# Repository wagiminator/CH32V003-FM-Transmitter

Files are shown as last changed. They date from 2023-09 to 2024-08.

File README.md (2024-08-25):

# CH32V003 Stereo FM Transmitter
With the portable Li-Ion battery powered Stereo FM Transmitter you can transmit audio of any kind. Simply plug your audio source into the 3.5mm audio jack, set the desired frequency, and then tune any standard FM radio receiver to receive the signal. This device is equipped with cost-effective components, including a CH32V003J4M6 32-bit RISC-V microcontroller, a KT0803K/L transmitter IC, a 128x32 pixel OLED display (SSD1306), and a Li-Ion battery charger (TP4054).

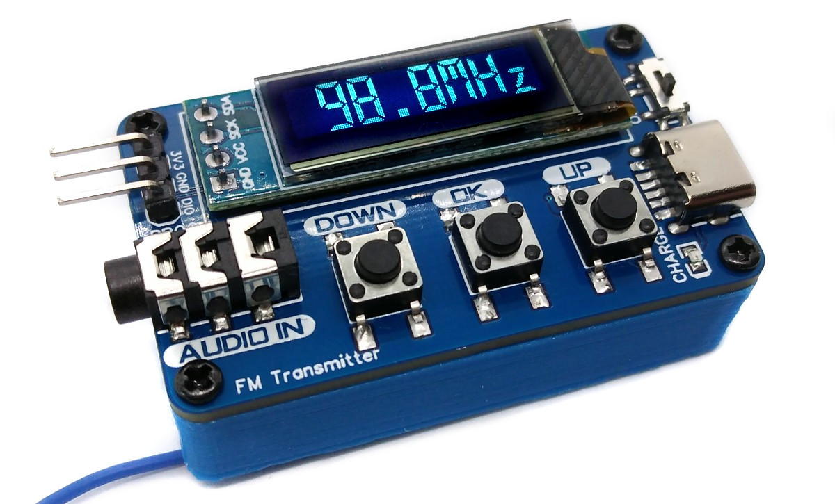
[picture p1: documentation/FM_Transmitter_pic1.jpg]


# Hardware
## Schematic
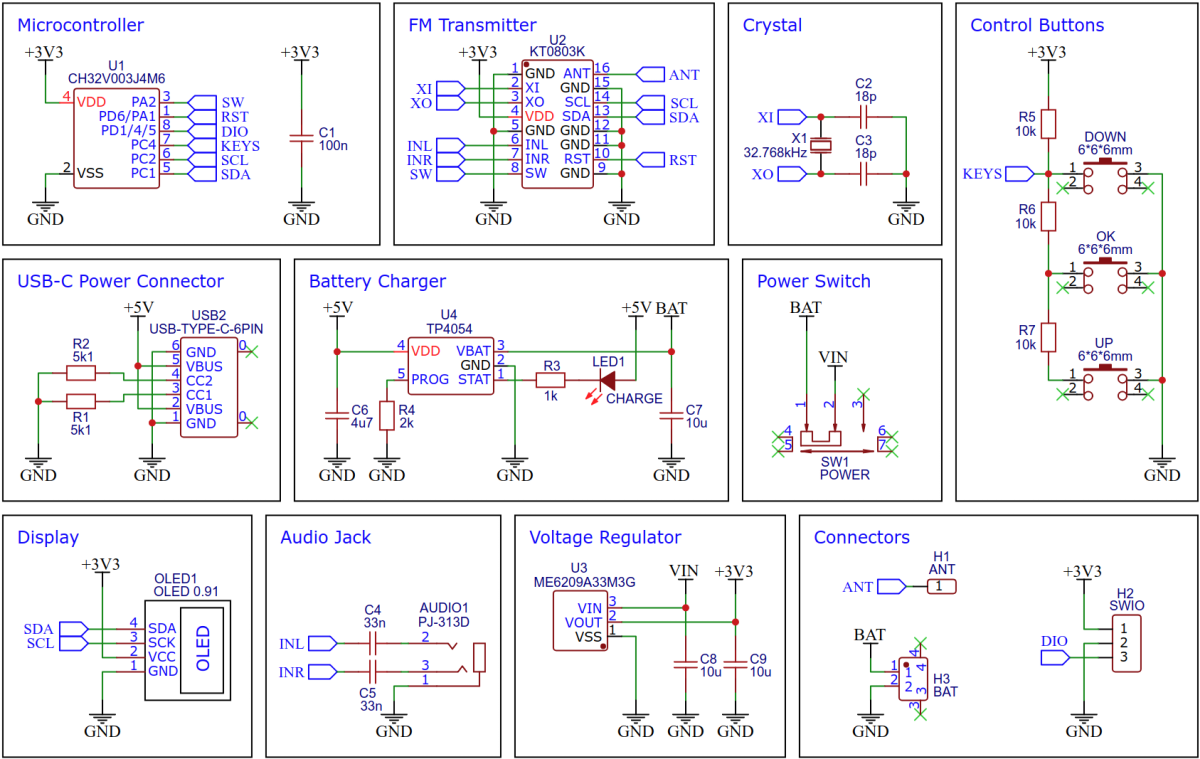
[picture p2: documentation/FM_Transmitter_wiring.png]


## The CH32V003 Family of 32-bit RISC-V Microcontrollers
The CH32V003 series is a collection of industrial-grade general-purpose microcontrollers that utilize the QingKe RISC-V2A core design supporting the RV32EC instruction set. These microcontrollers are equipped with various features such as a 48MHz system main frequency, 16KB flash, 2KB SRAM, 2.7V - 5.5V supply voltage support, a single-wire serial debug interface, low power consumption, and an ultra-small package. Additionally, the CH32V003 series includes a built-in set of components including a DMA controller, a 10-bit ADC, op-amp comparators, multiple timers, and standard communication interfaces such as USART, I2C, and SPI.

## KT0803K or KT0803L Radio-Station-on-a-Chip
The KT0803K/L is a low cost Monolithic Digital Stereo FM Transmitter, designed to process high-fidelity stereo audio signal and transmit modulated FM signal over a short range. The KT0803K/L features dual 20-bit ΔΣ audio ADCs, a high-fidelity digital stereo audio processor and a fully integrated radio frequency (RF) transmitter. An on-chip low-drop-out regulator (LDO) allows the chip to be integrated in a wide range of low-voltage battery-operated systems with power supply ranging from 1.6V to 3.6V. The KT0803K/L can be controlled via its I²C interface.

## TP4054 Li-Ion Battery Charge IC
The TP4054 is a complete constant-current/constant-voltage linear charger for single cell lithium-ion batteries. Its small package and low external component count make the TP4054 ideally suited for portable applications.

## ME6209 3.3V Linear Voltage Regulator
The ME6209 series are a group of positive voltage output, three–pin regulator, that provide a high current (max 250mA) even when the input/output voltage differential is small (80mV dropout voltage). Low power consumption (3µA quiescent current) and high accuracy (+/-2%) is achieved through CMOS technology. They allow input voltages as high as 18V.

## SSD1306 OLED Display Module
A low-cost SSD1306 4-pin I2C 128x32 pixels 0.91-inch OLED module is used as the display device. Make sure to acquire one with the correct pinout!

## Building Instructions
1. Take the Gerber files (the *zip* file inside the *hardware* folder) and upload them to a PCB (printed circuit board) manufacturer of your choice (e.g., [JLCPCB](https://jlcpcb.com/)). They will use these files to create the circuit board for your device and send it to you.
2. Once you have the PCB, you can start soldering the components onto it. Use the BOM (bill of materials) and schematic as a guide to make sure everything is connected correctly. You can find the corresponding files in the *hardware* folder. Remove the plastic part from the pin header of the OLED, trim the pins, and solder the OLED module flush onto the PCB. Solder the wire antenna to the corresponding pad on the board. A 75cm (30" = λ / 4) long 28AWG flexible silicone insulated wire works very well.

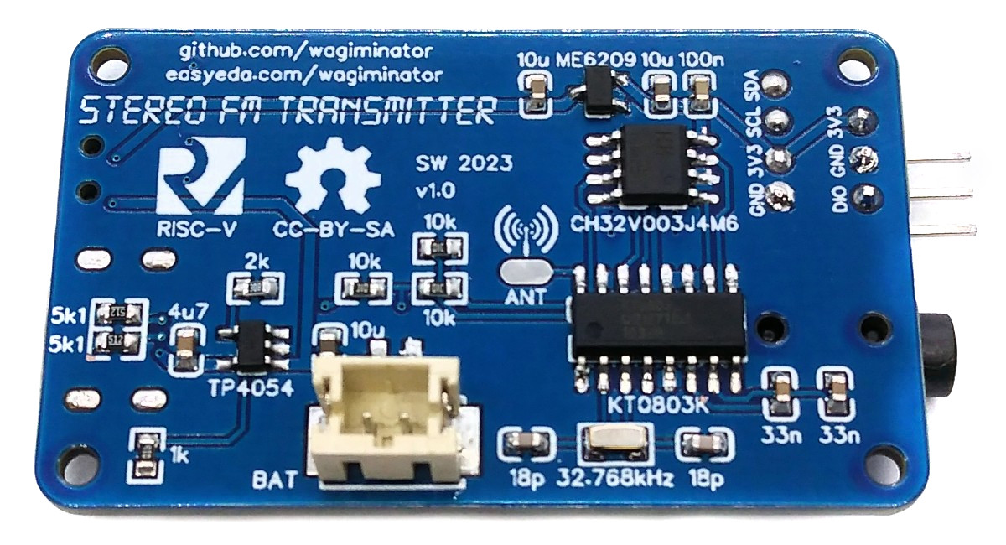
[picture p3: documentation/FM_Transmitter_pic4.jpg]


3. Upload the firmware by following the instructions in the next section (see below).
4. To create the case for your device, use the *stl* files in the *3dprint* folder with your 3D printer. Glue the battery into the case with double-sided tape. Thread the wire antenna through the small hole in the housing.

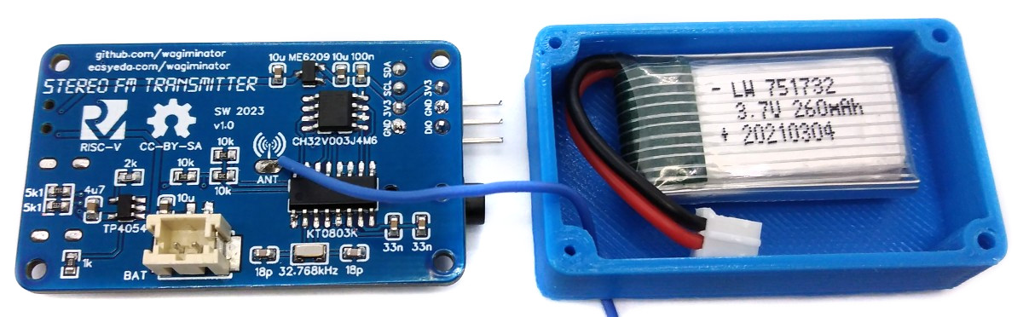
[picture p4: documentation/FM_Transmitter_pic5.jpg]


5. Connect the battery to the JST connector on the board. Pay attention to the correct polarity, unfortunately there is no standard here! Place the board on the case and screw it with four M2x5mm self-tapping screws.

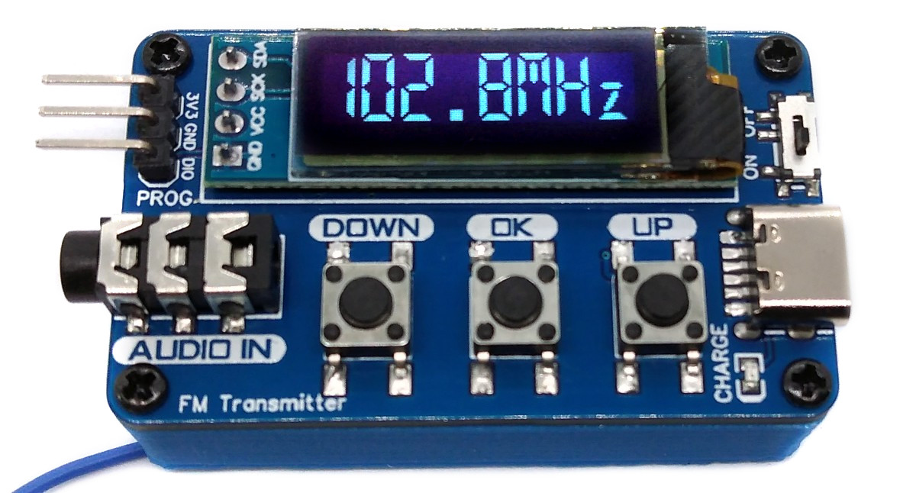
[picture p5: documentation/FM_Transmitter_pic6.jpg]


# Software
## Programming and Debugging Device
To program the CH32V003 microcontroller, you will need a special programming device which utilizes the proprietary single-wire serial debug interface (SDI). The [WCH-LinkE](http://www.wch-ic.com/products/WCH-Link.html) (pay attention to the "E" in the name) is a suitable device for this purpose and can be purchased commercially for around $4. This debugging tool is not only compatible with the CH32V003 but also with other WCH RISC-V and ARM-based microcontrollers.



To use the WCH-LinkE on Linux, you need to grant access permissions beforehand by executing the following commands:
```
echo 'SUBSYSTEM=="usb", ATTR{idVendor}=="1a86", ATTR{idProduct}=="8010", MODE="666"' | sudo tee /etc/udev/rules.d/99-WCH-LinkE.rules
echo 'SUBSYSTEM=="usb", ATTR{idVendor}=="1a86", ATTR{idProduct}=="8012", MODE="666"' | sudo tee -a /etc/udev/rules.d/99-WCH-LinkE.rules
sudo udevadm control --reload-rules
```

On Windows, if you need to you can install the WinUSB driver over the WCH interface 1 using the [Zadig](https://zadig.akeo.ie/) tool.

To upload the firmware, you need to ensure that the FM Transmitter is switched off or the battery is removed. Then, you should make the following connections to the WCH-LinkE:

```
WCH-LinkE    FM Transmitter
+-------+      +-------+
|  SWDIO| <--> |DIO    |
|    GND| ---> |GND    |
|    3V3| ---> |3V3    |
+-------+      +-------+
```

If the blue LED on the WCH-LinkE remains illuminated once it is connected to the USB port, it means that the device is currently in ARM mode and must be switched to RISC-V mode initially. There are a few ways to accomplish this:
- You can utilize the Python command-line tool [rvprog](https://pypi.org/project/rvprog/) (with *-v* option).
- Alternatively, you can select "WCH-LinkRV" in the software provided by WCH, such as MounRiver Studio or WCH-LinkUtility.
- Another option is to hold down the ModeS button on the device while plugging it into the USB port.

More information can be found in the [WCH-Link User Manual](http://www.wch-ic.com/downloads/WCH-LinkUserManual_PDF.html).

## Compiling and Uploading Firmware using the Makefile
### Linux
Install the toolchain (GCC compiler, Python3, and rvprog):
```
sudo apt install build-essential libnewlib-dev gcc-riscv64-unknown-elf
sudo apt install python3 python3-pip
pip install rvprog
```

Switch off the FM Transmitter or remove the battery. Connect the FM Transmitter via the 3-pin PROG header to the WCH-LinkE programming device. Open a terminal and navigate to the folder with the *makefile*. Run the following command to compile and upload:
```
make flash
```

### Other Operating Systems
Follow the instructions on [CNLohr's ch32v003fun page](https://github.com/cnlohr/ch32v003fun/wiki/Installation) to set up the toolchain on your respective operating system (for Windows, use WSL). Also, install [Python3](https://www.pythontutorial.net/getting-started/install-python/) and [rvprog](https://pypi.org/project/rvprog/). Compile and upload with "make flash". Note that I only have Debian-based Linux and have not tested it on other operating systems.

## Compiling and Uploading Firmware using PlatformIO
- Install [PlatformIO](https://platformio.org) and [platform-ch32v](https://github.com/Community-PIO-CH32V/platform-ch32v). Follow [these instructions](https://pio-ch32v.readthedocs.io/en/latest/installation.html) to do so. Linux/Mac users may also need to install [pyenv](https://realpython.com/intro-to-pyenv).
- Click on "Open Project" and select the firmware folder with the *platformio.ini* file.
- Switch off the FM Transmitter or remove the battery. Connect the FM Transmitter via the 3-pin PROG header to the WCH-LinkE programming device. Then click "Upload".

## Uploading pre-compiled Firmware Binary
WCH offers the free but closed-source software [WCH-LinkUtility](https://www.wch.cn/downloads/WCH-LinkUtility_ZIP.html) to upload the precompiled hex-file with Windows. Select the "WCH-LinkRV" mode in the software, open the *fm_transmitter.hex* file in the *bin* folder and upload it to the microcontroller.

Alternatively, there is an open-source tool called [minichlink](https://github.com/cnlohr/ch32v003fun/tree/master/minichlink) developed by Charles Lohr (CNLohr). It can be used with Windows, Linux and Mac.

If you have installed [Python3](https://www.pythontutorial.net/getting-started/install-python/) on your system, you can also use the platform-independent open-source command-line tool [rvprog](https://pypi.org/project/rvprog/) for uploading:
```
rvprog -f bin/fm_transmitter.bin
```

# Operating Instructions
1. Make sure that the wire antenna is laid as straight as possible horizontally or vertically.
2. Turn on the transmitter using the power switch.
3. Use the OK key to switch between transmitter frequency and audio gain display/control mode.
4. Use the UP or DOWN key to increase/decrease frequency/gain.
5. If the battery is weak, recharge it via the USB-C port.

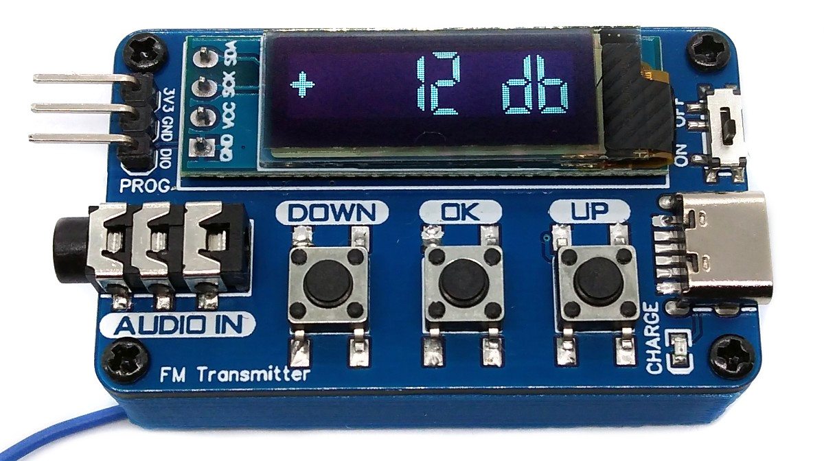
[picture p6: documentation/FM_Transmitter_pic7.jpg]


If you don't have an FM radio receiver and/or you want to build one yourself, take a look [here](https://github.com/wagiminator/CH32V003-FM-Receiver).

# References, Links and Notes
- [EasyEDA Design Files](https://oshwlab.com/wagiminator)
- [CNLohr: ch32003fun](https://github.com/cnlohr/ch32v003fun)
- [WCH: CH32V003 datasheets](http://www.wch-ic.com/products/CH32V003.html)
- [WCH: WCH-Link user manual](http://www.wch-ic.com/downloads/WCH-LinkUserManual_PDF.html)
- [WCH: Official Store on AliExpress](https://wchofficialstore.aliexpress.com)
- [KTMicro: KT0803K datasheet](https://www.elechouse.com/elechouse/images/product/FM%20Transmitter%20Module/KT0803K.pdf)
- [KTMicro: KT0803L datasheet](http://radio-z.ucoz.lv/kt_0803/KT0803L_V1.3.pdf)
- [Microne: ME6209 datasheet](https://datasheet.lcsc.com/lcsc/1811081822_MICRONE-Nanjing-Micro-One-Elec-ME6209A33M3G_C83508.pdf)
- [TP4054 datasheet](https://media.digikey.com/pdf/Data%20Sheets/UTD%20Semi%20PDFs/TP4054.pdf)
- [SSD1306 datasheet](https://cdn-shop.adafruit.com/datasheets/SSD1306.pdf)
- [128x32 OLED on Aliexpress](http://aliexpress.com/wholesale?SearchText=128+32+0.91+oled)
- [CH32V003 FM Radio Receiver](https://github.com/wagiminator/CH32V003-FM-Receiver)

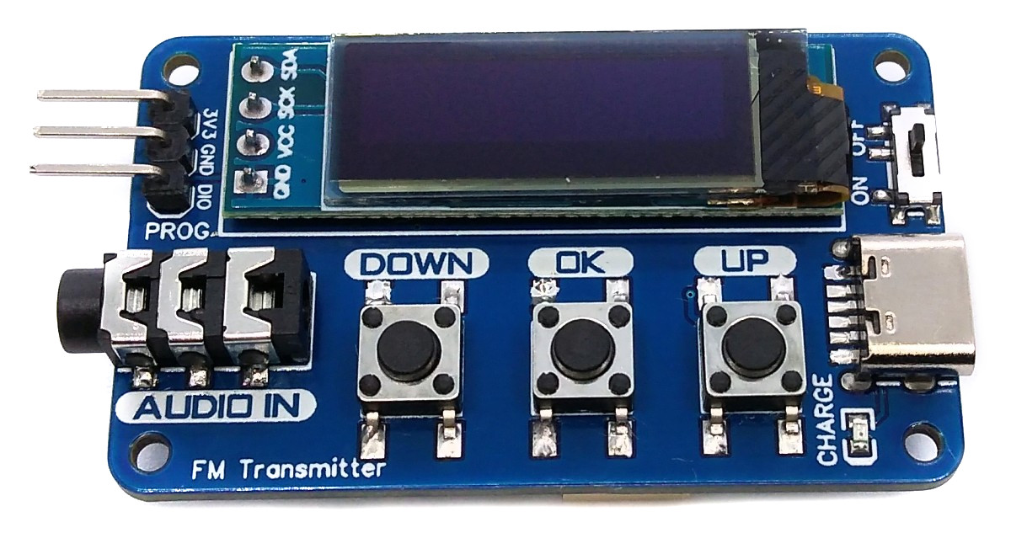
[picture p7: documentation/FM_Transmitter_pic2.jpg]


# License



This work is licensed under Creative Commons Attribution-ShareAlike 3.0 Unported License. 
(http://creativecommons.org/licenses/by-sa/3.0/)

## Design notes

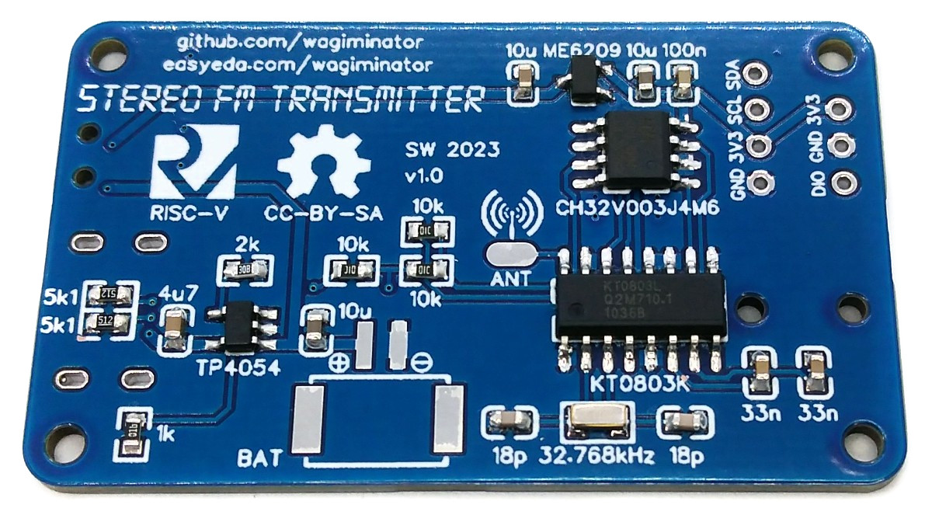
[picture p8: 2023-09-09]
documentation/FM_Transmitter_pic3.jpg

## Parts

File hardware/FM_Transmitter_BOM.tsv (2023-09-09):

ID | Name | Designator | Footprint | Quantity | Manufacturer Part | Manufacturer | Supplier | Supplier Part
1 | PJ-313D | AUDIO1 | AUDIO-SMD_PJ-313D | 1 | PJ-313D | HRO | LCSC | C95463
2 | 100n | C1 | C_0603 | 1 | CC0603KRX7R9BB104 | YAGEO | LCSC | C14663
3 | 18p | C2,C3 | C_0603 | 2 | CL10C180JB8NNNC | SAMSUNG(三星) | LCSC | C1647
4 | 33n | C4,C5 | C_0603 | 2 | CL10B333KB8NNNC | SAMSUNG(三星) | LCSC | C21117
5 | 4u7 | C6 | C_0603 | 1 | CL10A475KO8NNNC | SAMSUNG | LCSC | C19666
6 | 10u | C7,C8,C9 | C_0603 | 3 | CL10A106KP8NNNC | SAMSUNG | LCSC | C19702
7 | 6*6*6mm | DOWN,OK,UP | KEY-6.0*6.0 | 3 | SMD Tactile Switch6*6*6mm | ReliaPro | LCSC | C23873
8 | ANT | H1 | PAD_1 | 1 |  |  | LCSC | C81276
9 | SWIO | H2 | 210S-3X1/2.54 | 1 | Header2.54mm 1*3P | BOOMELE | LCSC | C49257
10 | BAT | H3 | CONN-SMD_2P_PH2.0_LT | 1 | PH2.0-2P | BOOMELE | LCSC | C64658
11 | CHARGE | LED1 | LED_0603 | 1 | KT-0603R | KENTO | LCSC | C2286
12 | OLED 0.91 | OLED1 | I2C OLED 0.91 | 1 | SSD1306 I2C OLED
13 | 5k1 | R1,R2 | 0603 | 2 | 0603WAF5101T5E | UniOhm | LCSC | C23186
14 | 1k | R3 | 0603 | 1 | 0603WAF1001T5E | UniOhm | LCSC | C21190
15 | 2k | R4 | 0603 | 1 | 0603WAF2001T5E | UniOhm | LCSC | C22975
16 | 10k | R5,R6,R7 | 0603 | 3 | 0603WAF1002T5E | UNI-ROYAL(厚声) | LCSC | C25804
17 | POWER | SW1 | SW-SMD_SS-1290L-GLL-1.5MM | 1 | SS-1290L-GL L=1.5mm | RI SHENG | LCSC | C695418
18 | CH32V003J4M6 | U1 | SOP-8_150MIL | 1 | CH32V003J4M6 | WCH(Jiangsu Qin Heng) | LCSC | C5346354
19 | KT0803K | U2 | SOP-16_150MIL | 1 |  | KTMicro
20 | ME6209A33M3G | U3 | SOT-23-3_W | 1 | ME6209A33M3G | MICRONE | LCSC | C83508
21 | TP4054 | U4 | SOT-23-5_BR | 1 | TP4054 | UMW(广东友台半导体) | LCSC | C668215
22 | USB-TYPE-C-6PIN | USB2 | USB-C-SMD-6P | 1 | TYPE-C-31-M-17 | Korean Hroparts Elec | LCSC | C283540
23 | 32.768kHz | X1 | OSC-SMD_3215 | 1 | AH03270014 | TXC Corp | LCSC | C409356

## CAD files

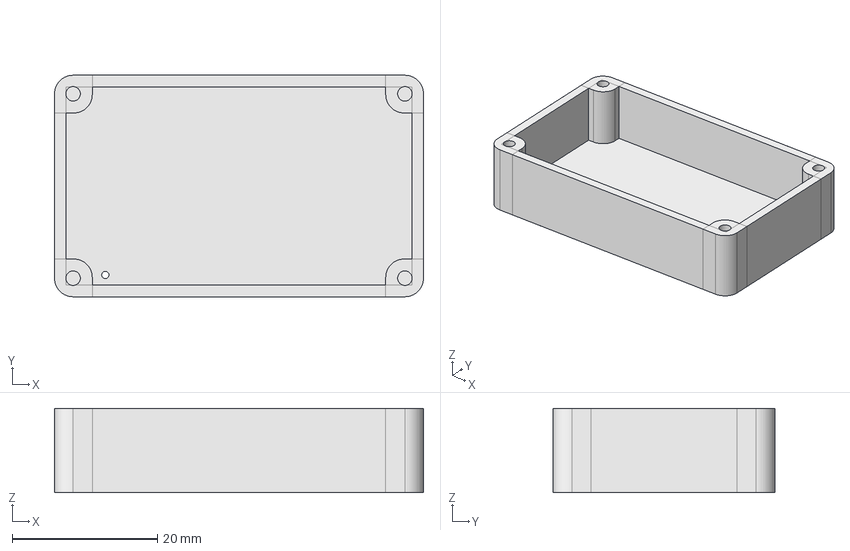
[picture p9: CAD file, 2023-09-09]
3dprint/FM_Transmitter.fcstd
50.8 x 30.5 x 11.6 mm

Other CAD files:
3dprint/FM_Transmitter.stl

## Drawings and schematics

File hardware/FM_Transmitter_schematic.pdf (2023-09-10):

# RST 10 GND 11 GND 12 SDA 13 SCL 14 GND 15 ANT 16

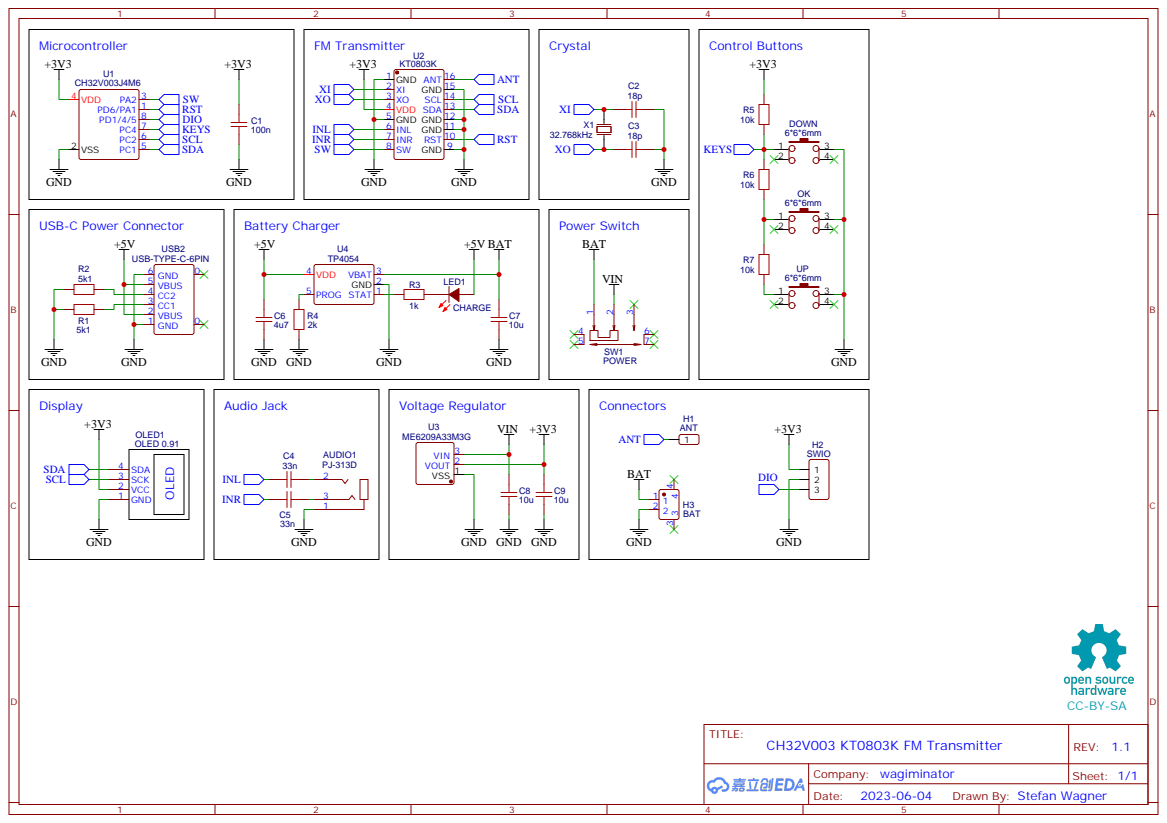
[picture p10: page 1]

Drawn By: Stefan Wagner

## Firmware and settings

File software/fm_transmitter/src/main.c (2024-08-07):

// ===================================================================================
// Project:   CH32V003 + KT0803 K/L FM Transmitter
// Version:   v1.1
// Year:      2023
// Author:    Stefan Wagner
// Github:    https://github.com/wagiminator
// EasyEDA:   https://easyeda.com/wagiminator
// License:   http://creativecommons.org/licenses/by-sa/3.0/
// ===================================================================================
//
// Description:
// ------------
// Pocket Stereo FM Transmitter.
//
// References:
// -----------
// - CNLohr ch32v003fun: https://github.com/cnlohr/ch32v003fun
// - WCH Nanjing Qinheng Microelectronics: http://wch.cn
//
// Compilation Instructions:
// -------------------------
// - Make sure GCC toolchain (gcc-riscv64-unknown-elf, newlib) and Python3 with rvprog
//   are installed. In addition, Linux requires access rights to WCH-LinkE programmer.
// - Connect the WCH-LinkE programmer to the PROG-header of the device.
// - Run 'make flash'.


// ===================================================================================
// Libraries, Definitions and Macros
// ===================================================================================
#include <system.h>           // system functions
#include <gpio.h>             // GPIO functions
#include <kt0803.h>           // KT0803 functions
#include <ssd1306_txt.h>      // OLED functions

#define PIN_SW    PA2         // KT0803 switch on/off
#define PIN_RST   PA1         // KT0803 reset (active low)
#define PIN_KEYS  PC4         // Control keys

uint8_t  display = 0;         // current display/control mode (0: frequency, 1: gain)
uint8_t  gain = 3;            // current gain (0..6)
uint16_t freq = 988;          // current frequency (in 100kHz steps, 988 means 98.8Mhz) 

// ===================================================================================
// OLED Bitmaps
// ===================================================================================

// "MHz" 44x32 pixel segment font
const uint8_t OLED_MHZ[] = {
  0xFC, 0xF9, 0xF3, 0x07, 0x07, 0xE7, 0xF7, 0xE7, 0x07, 0x07, 0xF3, 0xF9, 0xFC, 0x00, 0x00, 0x00,
  0xFC, 0xF8, 0xF0, 0x00, 0x00, 0x00, 0x00, 0x00, 0x00, 0x00, 0xF0, 0xF8, 0xFC, 0x00, 0x00, 0x00,
  0x00, 0x00, 0x00, 0x00, 0x00, 0x00, 0x00, 0x00, 0x00, 0x00, 0x00, 0x00, 
  0x7F, 0x3F, 0x1F, 0x00, 0x00, 0x1F, 0x3F, 0x1F, 0x00, 0x00, 0x1F, 0x3F, 0x7F, 0x00, 0x00, 0x00,
  0x7F, 0x3F, 0x9F, 0xC0, 0xC0, 0xC0, 0xC0, 0xC0, 0xC0, 0xC0, 0x9F, 0x3F, 0x7F, 0x00, 0x00, 0x00,
  0x00, 0x80, 0xC0, 0xC0, 0xC0, 0xC0, 0xC0, 0xC0, 0xC0, 0x80, 0x00, 0x00, 
  0xFF, 0xFE, 0xFC, 0x00, 0x00, 0x00, 0x00, 0x00, 0x00, 0x00, 0xFC, 0xFE, 0xFF, 0x00, 0x00, 0x00,
  0xFF, 0xFE, 0xFC, 0x01, 0x01, 0x01, 0x01, 0x01, 0x01, 0x01, 0xFC, 0xFE, 0xFF, 0x00, 0x00, 0x00,
  0x00, 0x00, 0x01, 0x81, 0xE1, 0xF9, 0x7D, 0x1D, 0x01, 0x00, 0x00, 0x00, 
  0x1F, 0x0F, 0x07, 0x00, 0x00, 0x00, 0x00, 0x00, 0x00, 0x00, 0x07, 0x0F, 0x1F, 0x00, 0x00, 0x00,
  0x1F, 0x0F, 0x07, 0x00, 0x00, 0x00, 0x00, 0x00, 0x00, 0x00, 0x07, 0x0F, 0x1F, 0x00, 0x00, 0x00,
  0x40, 0x60, 0x76, 0x77, 0x73, 0x71, 0x70, 0x70, 0x70, 0x60, 0x40, 0x00
};

// "db" 29x32 pixel segment font
const uint8_t OLED_DB[] = {
  0x00, 0x00, 0x00, 0x00, 0x00, 0x00, 0x00, 0x00, 0x00, 0x00, 0xF0, 0xF8, 0xFC, 0x00, 0x00, 0x00,
  0xFC, 0xF8, 0xF0, 0x00, 0x00, 0x00, 0x00, 0x00, 0x00, 0x00, 0x00, 0x00, 0x00, 
  0x00, 0x00, 0x80, 0xC0, 0xC0, 0xC0, 0xC0, 0xC0, 0xC0, 0xC0, 0x9F, 0x3F, 0x7F, 0x00, 0x00, 0x00,
  0x7F, 0x3F, 0x9F, 0xC0, 0xC0, 0xC0, 0xC0, 0xC0, 0xC0, 0xC0, 0x80, 0x00, 0x00, 
  0xFF, 0xFE, 0xFC, 0x01, 0x01, 0x01, 0x01, 0x01, 0x01, 0x01, 0xFC, 0xFE, 0xFF, 0x00, 0x00, 0x00,
  0xFF, 0xFE, 0xFC, 0x01, 0x01, 0x01, 0x01, 0x01, 0x01, 0x01, 0xFC, 0xFE, 0xFF, 
  0x1F, 0x4F, 0x67, 0x70, 0x70, 0x70, 0x70, 0x70, 0x70, 0x70, 0x67, 0x4F, 0x1F, 0x00, 0x00, 0x00,
  0x1F, 0x4F, 0x67, 0x70, 0x70, 0x70, 0x70, 0x70, 0x70, 0x70, 0x67, 0x4F, 0x1F
};

// "-" 13x32 pixel segment font
const uint8_t OLED_MINUS[] = {
  0x00, 0x00, 0x00, 0x00, 0x00, 0x00, 0x00, 0x00, 0x00, 0x00, 0x00, 0x00, 0x00, 
  0x00, 0x00, 0x80, 0xC0, 0xC0, 0xC0, 0xC0, 0xC0, 0xC0, 0xC0, 0x80, 0x00, 0x00, 
  0x00, 0x00, 0x00, 0x01, 0x01, 0x01, 0x01, 0x01, 0x01, 0x01, 0x00, 0x00, 0x00, 
  0x00, 0x00, 0x00, 0x00, 0x00, 0x00, 0x00, 0x00, 0x00, 0x00, 0x00, 0x00, 0x00
};

// "+" 13x32 pixel segment font
const uint8_t OLED_PLUS[] = {
  0x00, 0x00, 0x00, 0x00, 0x00, 0x00, 0x00, 0x00, 0x00, 0x00, 0x00, 0x00, 0x00, 
  0x00, 0x80, 0xC0, 0xC0, 0xC0, 0xFC, 0xFE, 0xFC, 0xC0, 0xC0, 0xC0, 0x80, 0x00, 
  0x00, 0x00, 0x01, 0x01, 0x01, 0x1F, 0x3F, 0x1F, 0x01, 0x01, 0x01, 0x00, 0x00, 
  0x00, 0x00, 0x00, 0x00, 0x00, 0x00, 0x00, 0x00, 0x00, 0x00, 0x00, 0x00, 0x00
};

// ===================================================================================
// OLED Update Function
// ===================================================================================
void OLED_update(void) {
  OLED_cursor(0, 0);

  // Display current volume gain level
  if(display) {
    OLED_drawBitmap((gain < 3 ? OLED_MINUS : OLED_PLUS), 13, 4);
    if      (gain == 3)                 OLED_printSegment( 0, 4, 1, 0);
    else if((gain == 0) || (gain == 6)) OLED_printSegment(12, 4, 1, 0);
    else if((gain == 1) || (gain == 5)) OLED_printSegment( 8, 4, 1, 0);
    else                                OLED_printSegment( 4, 4, 1, 0);
    OLED_clearRect(21, 32);
    OLED_drawBitmap(OLED_DB, 29, 4);
  }

  // Display current transmitter frequency
  else {
    OLED_printSegment(freq, 4, 1, 1);
    OLED_clearRect(13, 32);
    OLED_drawBitmap(OLED_MHZ, 44, 4);
  }
}

// ===================================================================================
// Button Read Function
// ===================================================================================
enum { KEY_NO, KEY_UP, KEY_OK, KEY_DOWN };
uint16_t KEY_ADC[] = { 850, 590, 250, 0 };

uint8_t KEY_read(void) {
  uint8_t  ckey = 0;
  uint16_t ckeyval = ADC_read();
  while(ckeyval < KEY_ADC[ckey]) ckey++;
  return ckey;
}

// ===================================================================================
// Main Function
// ===================================================================================
int main(void) {
  // Lokal variables
  uint8_t  i;
  uint8_t  key;
  uint8_t  keydelay;

  // Setup pins
  PIN_output(PIN_SW);
  PIN_output(PIN_RST);
  PIN_input_AN(PIN_KEYS);
  PIN_high(PIN_SW);
  PIN_high(PIN_RST);

  // Setup internal peripherals
  I2C_init();
  ADC_init();
  ADC_slow();
  ADC_input(PIN_KEYS);

  // Setup external peripherals
  OLED_init();
  OLED_clear();
  OLED_update();
  DLY_ms(500);
  KT_setFreq(freq);
  KT_setGain(gain);

  // Loop
  while(1) {
    // Read current key
    key = KEY_read();

    // Volume gain display/control mode
    if(display) {
      switch(key) {
        case KEY_UP:    if(gain < 6) KT_setGain(++gain); break;
        case KEY_DOWN:  if(gain > 0) KT_setGain(--gain); break;
        case KEY_OK:    display = 0; break;
        default:        break;
      }
      if(key) {
        OLED_update();
        while(KEY_read());
        DLY_ms(10);
      }
    }

    // Transmitter frequency display/control mode
    else {
      switch(key) {
        case KEY_UP:    freq++; break;
        case KEY_DOWN:  freq--; break;
        case KEY_OK:    display++; OLED_update(); while(KEY_read()); DLY_ms(10); break;
        default:        keydelay = 50; break;
      }
      if(freq != KT_getFreq()) {
        if(freq < KT_FREQ_MIN) freq = KT_FREQ_MAX;
        if(freq > KT_FREQ_MAX) freq = KT_FREQ_MIN;
        KT_setFreq(freq);
        OLED_update();
        i = keydelay;
        while((i--) && (KEY_read())) DLY_ms(10);
        keydelay = 5;
      }
    }
  }
}
